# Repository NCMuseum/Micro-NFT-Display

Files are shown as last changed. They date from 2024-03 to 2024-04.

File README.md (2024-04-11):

An ESP32 based video player, that plays files from an SD card. Designed to play to a 128x64px OLED Screen.

# Parts List

Solderless Breadboard similar to this **https://core-electronics.com.au/solderless-breadboard-830-tie-point-zy-102.html**

LOLIN D32 Pro ESP32 Dev Board **https://www.aliexpress.com/item/32883116057.html**

Graphical OLED Display (128x64)  **https://www.pololu.com/product/3760**

SD Card to fit your animations

1 x 18650 Lithium Ion Cell (2600mah)

1 x power switch

Bunch of cabling

Optional Stand can be 3D printed from the STL in the "Design Files" folder

# Libraries Used

The EPS32 PNG Lib is included in the project folder & does not need to be installed as a library **https://github.com/lagunax/ESP32-upng** - modified to work with SD card instead of SPIFFS on the ESP32

The POLOLU OLED Lib needs to be installed in your Arduino Libraries folder https://github.com/pololu/pololu-oled-arduino

# Creating an animation file set from any video file

The ESP32 is not powerfull enough to play actual video files like .mp4, but we can preprocess any video file as sequenced PNG images. To do this you will need VLC Player **https://www.videolan.org/** After its installed you will need to configure on the Video Filters to output PNG files for you. Follow these steps to set it up:

1.  Open VLC Player
2.  Click on the TOOLS menu and select PREFERENCES
3.  Tick the "ALL" radio button in SHOW SETTINGS so you can see all teh settings at once
4.  Ont the left pane, scroll down to the bottom and DOUBLE CLICK on VIDEO
5.  On the right PANE tick "SCENE VIDEO FILTER"
6.  On the left pane scroll down to and click on "SCENE FILTER"
7.  On the right pane set the Image Format to "png"
8.  Image width to 128
9.  Image height to 64
10.  Filename prefix to whatever you want your animation to be called eg.. "MyAnimation_"
11.  If you want the PNG files output to specific folder enter it in the "Directory Path Prefix" field
12.  Set the recording Ration to 1
13.  Hit Save and restart VLC Player

To create your animations PNG files simply laod your video and hit play. The PNG files will be written to iether the source directory of your animation or the "Directory Path Prefix" you set in step 11. Once you have all your PNG files, create a folder on the SD card with the same name as you set in step 10. eg.. "MyAnimation". Move all the PNG files into this folder. 

Repeat the above for all your video files, but be sure to chagne the animation name prefix in step 11 and output folder path in step 11.

# Animation Pre requisites

Your animations must be in .png 24BIT colour, no transparency or anythhing else fancy. VLC will output by default as this
Make sure your source material is iether BW or Greyscale as the end render is in 1bit BW on the OLED Screen
The animations dimensions must be 128*64px 
The file names must look like this "AnimationName_00000.png" . Each animation can have up to a maximum of 99,999 frames.
The 1st frame must start at "_00001"
(You can also set a frame delay in the playlist file below if you want to slow down or speed up the playback)

# SDCARD Pre requisites

Format the SDCARD as one FAT32 Volume. Size isnt important. The root of the SDCard needs to have the following structure:
NO SPECIAL CHARECTORS IN ANIMATION NAMES

````
[DIR] AnimationOne
[DIR] AnimationTwo
[DIR] AnimationThree
[FILE] playlist
````

Example layout of one of the animation folders:

````
/AnimationOne
AnimationOne_00001.png
AnimationOne_00002.png
AnimationOne_00003.png
AnimationOne_00004.png
AnimationOne_..............
AnimationOne_00100.png
````

The Playlist file is set up as follows:
````
[Case Senstive Animation Name],[Number of Frame Files],[Delay in MILISECONDS between each frame];
[Case Senstive Animation Name],[Number of Frame Files],[Delay in MILISECONDS between each frame];
[Case Senstive Animation Name],[Number of Frame Files],[Delay in MILISECONDS between each frame];
....
````

Example layout of the "playlist" file

````
AnimationOne,100,10;AnimationTwo,200,20;AnimationThree,50,100;
````
You can set up a playlist toplay the same animation mulitple times, with any per frame delay and even reduce the animation frame count. EG.. this will play animation 1 (which has 100 frames in total) once at full speed, then at a slower speed, then only the 1st 50 frames at full speed

````
AnimationOne,100,1;AnimationOne,100,50;AnimationOne,50,1;
````

# Pinout for the Lolin D32 Pro ESP32 module

Micro CD Card PinOut for the Wemos D32 Pro as taken from  **https://www.wemos.cc/en/latest/_static/files/sch_d32_pro_v2.0.0.pdf** these are allready hardwired on this module

````
NS		1	NC
/CS		2	IO    04	TF_CS
DI		3	IO    23	MOSI
VDD		4	3.3V
CLK		5	IO    18	SCK
VSS		6	GND
D0		7	IO    19	MISO
RSV		8	NC
CD(1)	G	GND
````

PINOUT for OLED Screen

````
SCREEN  ESP32 Pin
VCC     +5V
GND     GND
CLK     22
MOS     26
RES     0
DC      21
CS      27
````

# Boot Up Flow

1.  Insert the SD CARD and power on
2.  The Pre prosessor will RUN over the playlist and compile a .STREAM file for each animation. You will see a new folder for each animation called "AnimationNameSTREAM" and inside it will be the stream file named "AnimationName.STREAM". The OLED screen will display a prgress bar for each animation as they are beeing processed. The preprocess is SLOW especialy with more than 100 files for each animation, however this step is only done once
3.  After all animation folders are processed the ESP32 will start playing the streams in the order listed in the file 'playlist'. You can put multiple entries for the same animation. Each animation has 2 options. Number of frames in the animation folder and the delay in MILISECONDS between each frame. 1ms delay is good for very smooth frame rates.

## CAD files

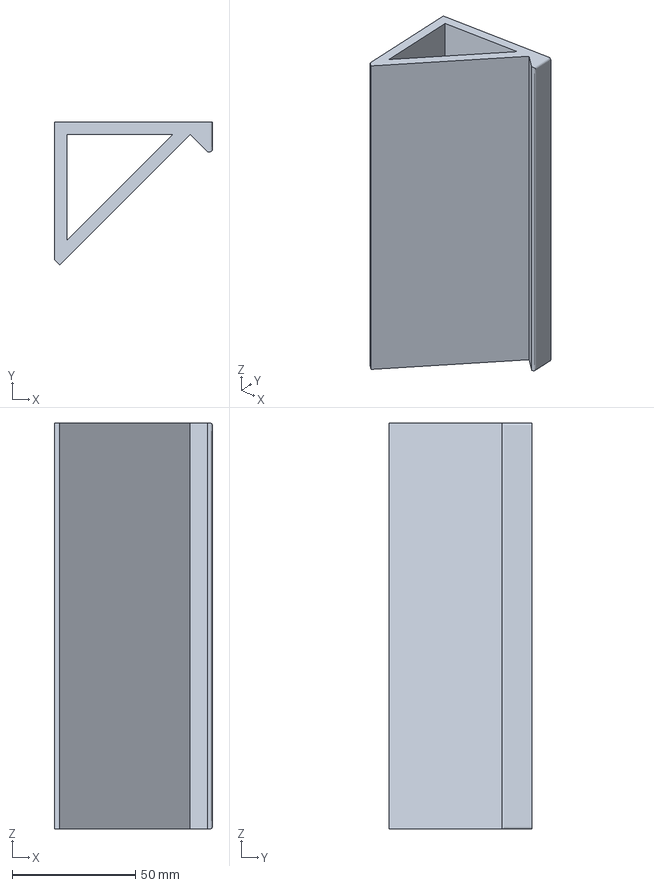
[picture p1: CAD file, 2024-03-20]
Design Files/MicroNFTDisplay_Stand.3mf
64.2 x 58.0 x 165.0 mm

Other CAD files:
Design Files/Stand.stl

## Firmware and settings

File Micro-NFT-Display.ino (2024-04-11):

/*
Micro CD Card PinOut for the Wemos D32 Pro as taken from 
https://www.wemos.cc/en/latest/_static/files/sch_d32_pro_v2.0.0.pdf

NS		1	NC
/CS		2	IO    04	TF_CS
DI		3	IO    23	MOSI
VDD		4	3.3V
CLK		5	IO    18	SCK
VSS		6	GND
D0		7	IO    19	MISO
RSV		8	NC
CD(1)	G	GND

PINOUT for OLED Screen
VCC     +5V
GND     GND
CLK     22
MOS     26
RES     0
DC      21
CS      27
 */

#include <WiFi.h>
#include "SPI.h"
#include <PololuOLED.h>
#include "FS.h"
#include "SD.h"
#include <string>
#include "upng.h"
#include "animationQue.h"

//Bitmaping Data
const byte rows=64, cols=128;    //rows = HEIGHT(Y)  cols = WIDTH(X)

//Colour Data
byte tempColour[3] = {0,0,0};

//Counters
unsigned short int cIndex=0, secondaryCIndex=0;
unsigned short int yCnt=0, xCnt=0;

//File Paths
char playListFile[] = "/playlist";
char integerCharString[] = "00000";

//PNG stuff
upng_t* upng;
unsigned short int xCount, yCount, imageSize, bufferIndex=0, testCnt=0;

//Card Stuff
uint8_t cardType=0;
long cardSize=0;

//Display
//The pins are specified in this order: CLK, MOS, RES, DC, CS.
PololuSH1106 display(22, 26, 0, 21, 27);
uint8_t graphics[1024];

//Pre Processor
File outputStream;
animationQue globalAnimationQue;

void setup()
{
  //Turn off WIFI we do not need it here
  WiFi.mode(WIFI_OFF); 
  
  //Init Serial
  Serial.begin(115200);
  Serial.printf("\r\n\r\n\r\nSystem Booting....\r\n");

  //Set up the OLED Display
  display.setLayout11x4WithGraphics(graphics);
  memset(graphics, 0, sizeof(graphics));
  display.noAutoDisplay();
  display.clear();
  display.display();

  //Init File System
  initFS();
  
  //Populate Animation List from SD Card file /playlist
  compilePlaylist();
  
  //Pre Process Multiple Frames into 1 File Stream
  compileStream();

}

void initFS()
{
  Serial.printf("\r\n\tSetting up SD Card FS...");
  
  SPI.begin();
  //begin(18, 19, 23, 4)
  SPI.setFrequency(40000000);
  if(! SD.begin(SS, SPI, 40000000, "/sd", 5, false) )
  {
    Serial.printf("\r\n\tSD Card Mount Failed...");
    clearCanvas();
    display.clear();
    display.print("SD MNT FAIL");
    display.display();
    while(true)
    {
      yield();
    }
  }
  cardType = SD.cardType();
  if(cardType == CARD_NONE)
  {
    Serial.printf("\r\n\tNo SD card attached!");
    clearCanvas();
    display.clear();
    display.print("NO SD CARD");
    display.display();
    return;
  }
}

void compilePlaylist()
{
  char* tempAnimationName;
  char* tempAnimationLength;
  char* tempAnimationDelay;
  char* playListFileBuffer;
  unsigned short int animationCount=0;
  unsigned short int aCnt=0, startI=0, endI=0, needleIndex=0, tempLength=0;
  PLNODE* queLocater;
  
  outputStream = SD.open(playListFile, "r");
  playListFileBuffer = new char[ outputStream.size() ];
  outputStream.readBytes(playListFileBuffer, outputStream.size());
  outputStream.close();
  Serial.printf("\r\nReadin\t[%s]", playListFileBuffer);

  //Grab number of animations in playlist
  animationCount = countNeedles(playListFileBuffer, ';');
  Serial.printf("\r\nAnimation Count in playlist file\t[%d]", animationCount);
  
  for(aCnt=0; aCnt<animationCount; aCnt++)
  {
    //Serial.printf("\r\nADD..");
    //locate 1st ','  animationName
    needleIndex++;
    endI = findNeedleCount(playListFileBuffer, ',', needleIndex);
    tempLength = endI-startI;
    tempAnimationName = new char[ tempLength+1 ];
    clearCharArray(tempAnimationName);
    memcpy(tempAnimationName, playListFileBuffer+startI, tempLength);
    tempAnimationName[tempLength]='\0';
    //locate 2nd ','  frameCount
    startI = endI+1;
    needleIndex++;
    endI = findNeedleCount(playListFileBuffer, ',', needleIndex);
    tempLength = endI-startI;
    tempAnimationLength = new char[ tempLength+1 ];
    clearCharArray(tempAnimationLength);
    memcpy(tempAnimationLength, playListFileBuffer+startI, tempLength);
    tempAnimationLength[tempLength]='\0';
    startI = endI+1;
    //locate 3rd ';'  delay
    endI = findNeedleCount(playListFileBuffer, ';', aCnt+1);
    tempLength = endI-startI;
    tempAnimationDelay = new char[ tempLength+1 ];
    clearCharArray(tempAnimationDelay);
    memcpy(tempAnimationDelay, playListFileBuffer+startI, tempLength);
    tempAnimationDelay[tempLength]='\0';
    startI = endI+1;
    globalAnimationQue.add(tempAnimationName, atoi(tempAnimationLength), atoi(tempAnimationDelay));
    yield();
    Serial.printf("\r\nItem\t[%d]\t[%s][%d][%d]", aCnt, tempAnimationName, atoi(tempAnimationLength), atoi(tempAnimationDelay) );
    //clear memory
    delete tempAnimationName;
    delete tempAnimationLength;
    delete tempAnimationDelay;
  }
  
  //Dump Animations
  Serial.printf("\r\n\tTotal Nodes\t%d", globalAnimationQue.totalNodes);
  for(aCnt=0; aCnt<globalAnimationQue.totalNodes; aCnt++)
  {
    queLocater = globalAnimationQue.findByID(aCnt);
    if(queLocater!=NULL)
    {
      Serial.printf("\r\nAnimation\t[%d][%d]\tName[", aCnt, queLocater->_nodeID );
      Serial.print(queLocater->_animationName);
      Serial.printf("]\tFolder Path[");
      Serial.print(queLocater->_folderPath);
      Serial.printf("]\tFull Path[");
      Serial.print(queLocater->_fullPath);
      Serial.printf("]\tFrame Count[");
      Serial.print(queLocater->_totalFrames);
      Serial.printf("]\tFrame Delay[");
      Serial.print(queLocater->_frameDelay);
      Serial.printf("]");
    }
    else
    {
      Serial.printf("\r\n\tNode [%d] not found!", aCnt);
    }
  }

}

unsigned short int countFiles(char* dirName)
{
    unsigned short fileCount=0;
    char* folderPath = new char[strlen(dirName)+2];
    
    folderPath[0] = '/';
    memcpy(folderPath+1, dirName, strlen(dirName));
    folderPath[strlen(dirName)+1] = 0;
    
    
    File root = SD.open(folderPath);
    File file = root.openNextFile();
    while(file)
    {
        fileCount++;
        file = root.openNextFile();
    }
    return fileCount;
}

void clearCharArray(char* charArray)
{
  unsigned short int charCount=0;
  for(charCount=0; charCount<strlen(charArray); charCount++)
  {
    charArray[charCount]=0;
  }
}
short int findNeedleCount(char* haystack, char needle, unsigned short needleCount)
{
  unsigned short int hayCount=0, nCount=0;
  for(hayCount; hayCount<strlen(haystack); hayCount++)
  {
    if(haystack[hayCount]==needle)
    {
      nCount++;
      if(nCount==needleCount)
      {
        return hayCount;
      }
    }
  }
  return -1;
}
short int countNeedles(char* haystack, char needle)
{
  unsigned short int found;
  unsigned short int hayCount;
  
  for(hayCount=0; hayCount<strlen(haystack); hayCount++)
  {
    if(haystack[hayCount]==needle)
    {
      found++;
    }
  }
  return found;
}

void compileStream()
{
  unsigned short int plCounter=0, postFrameCounter=0, charArrayIndex=0, bytesWriten=0;
  byte dirExists=0, streamExists=0;
  char * tempPathArray;
  char endOfFileChars[] = "_00001.png";
  unsigned short int barWidth=98;
  double progressBar = 0;
  PLNODE* queLocater;
  
  for(plCounter=0; plCounter<globalAnimationQue.totalNodes; plCounter++)
  {
    queLocater = globalAnimationQue.findByID(plCounter);
    if(queLocater!=NULL)
    {
      //Details of animationa re in 
      //  queLocater->_animationName
      //  queLocater->_fullPath     - full path of stream file to output to
      charArrayIndex=0;
      tempPathArray = new char[strlen(queLocater->_animationName)+2+strlen(queLocater->_animationName)+strlen(endOfFileChars)+1];
      clearCharArray(tempPathArray);
      tempPathArray[charArrayIndex] = '/';
      // [/]
      charArrayIndex++;
      memcpy(tempPathArray+charArrayIndex, queLocater->_animationName, strlen(queLocater->_animationName));
      // [/name]
      charArrayIndex+=strlen(queLocater->_animationName);
      // [/name/]
      tempPathArray[charArrayIndex] = '/';
      charArrayIndex++;
      memcpy(tempPathArray+charArrayIndex, queLocater->_animationName, strlen(queLocater->_animationName));
      charArrayIndex+=strlen(queLocater->_animationName);
      // [/name/name]
      memcpy(tempPathArray+charArrayIndex, endOfFileChars, strlen(endOfFileChars));
      // [/name/name_00000.png]
      charArrayIndex+=strlen(endOfFileChars);
      tempPathArray[charArrayIndex] = '\0';
      
      Serial.printf("\r\nProceessing frames in[");
      Serial.print(tempPathArray);
      Serial.printf("]");
      //check if output stream file exists
      if(!SD.exists(queLocater->_fullPath))
      {
          Serial.printf("\r\n\tCreating folder\t[%s]", queLocater->_streamFolderPath);
          SD.mkdir(queLocater->_streamFolderPath);
          Serial.printf("\r\n\tOpening File\t[%s]", queLocater->_fullPath);
          outputStream = SD.open(queLocater->_fullPath, FILE_WRITE);
          if(!outputStream)
          {
            Serial.printf("\r\n\tERROR - Can not open stream file for writing....");
            outputStream.close();
          }
          else
          {
            //Reset Progress Bar Width
            clearCanvas();
            display.clear();
            display.print("Compiling:");
            drawRectangle(16, 20, barWidth, 40);
            display.display();
            progressBar=0;
            
            //build the stream file
            for(postFrameCounter=0; postFrameCounter<queLocater->_totalFrames; postFrameCounter++)
            {
              fileNameIncremeneter(postFrameCounter+1, tempPathArray);
              upng = upng_new_from_file(SD, tempPathArray);
              if (upng != NULL)
              {
                upng_decode(upng);
                Serial.printf("\r\nFrame\t%d\t%d\tBytes\t", postFrameCounter, upng_get_size(upng));
                bytesWriten = outputStream.write(upng_get_buffer(upng), upng_get_size(upng));
                upng_free(upng);
                Serial.printf("Written\t%d bytes", bytesWriten);
                progressBar = ((double)postFrameCounter/(double)queLocater->_totalFrames)*((double)barWidth);
                drawSolidRectangle(16, 20, (uint8_t)round(progressBar), 40);
                display.display();
              }
            }
            outputStream.close();
          }
      }
      else  
      {
        Serial.printf("\r\n\tStream already exists for this item.");
      }
      delete tempPathArray; 
    }
  }
}

void fileNameIncremeneter(unsigned short int fileNameIndex, char* filePathString)
{
  char renameAtPointer=0, renameCounter=0;
  char namePlacer = 95; //95="_"

  //find the "_" in the file name fileNamePointer
  for(renameCounter=0; renameCounter<strlen(filePathString); renameCounter++)
  {
    if(filePathString[renameCounter]==namePlacer)
    {
      renameAtPointer = renameCounter+1;
      break;
    }
  }
  itoa(fileNameIndex, integerCharString, 10);  
  if(fileNameIndex<10)
  {
    filePathString[renameAtPointer] = 48;
    filePathString[renameAtPointer+1] = 48;
    filePathString[renameAtPointer+2] = 48;
    filePathString[renameAtPointer+3] = 48;
    filePathString[renameAtPointer+4] = integerCharString[0];
  }
  else if(fileNameIndex<100)
  {
    filePathString[renameAtPointer] = 48;
    filePathString[renameAtPointer+1] = 48;
    filePathString[renameAtPointer+2] = 48;
    filePathString[renameAtPointer+3] = integerCharString[0];
    filePathString[renameAtPointer+4] = integerCharString[1];
  }
  else if(fileNameIndex<1000)
  {
    filePathString[renameAtPointer] = 48;
    filePathString[renameAtPointer+1] = 48;
    filePathString[renameAtPointer+2] = integerCharString[0];
    filePathString[renameAtPointer+3] = integerCharString[1];
    filePathString[renameAtPointer+4] = integerCharString[2];
  }
  else if(fileNameIndex<10000)
  {
    filePathString[renameAtPointer] = 48;
    filePathString[renameAtPointer+1] = integerCharString[0];
    filePathString[renameAtPointer+2] = integerCharString[1];
    filePathString[renameAtPointer+3] = integerCharString[2];
    filePathString[renameAtPointer+4] = integerCharString[3];
  }
  else if(fileNameIndex<100000)
  {
    filePathString[renameAtPointer] = integerCharString[0];
    filePathString[renameAtPointer+1] = integerCharString[1];
    filePathString[renameAtPointer+2] = integerCharString[2];
    filePathString[renameAtPointer+3] = integerCharString[3];
    filePathString[renameAtPointer+4] = integerCharString[4];
  }
}

void loop()
{
	unsigned short int streamCount=0;
	while(true)
	{
	  for(streamCount=0; streamCount<globalAnimationQue.totalNodes; streamCount++)
	  {
		  playStream(streamCount);
	  }
	  yield();
	}
}

void playStream(unsigned short int streamID)
{
  unsigned short int frameIndex=0, bufferIndex=0;
  char* frameBuffer = new char[rows*cols*3];
  unsigned short int pixelValue=0;
  unsigned short int colourLevelFilter = 300;

  PLNODE* queLocater = globalAnimationQue.findByID(streamID);
  if(queLocater!=NULL)
  {
    display.clear();
    Serial.printf("\r\nPlaying [");
    Serial.print(queLocater->_fullPath);
    Serial.printf("] Que Index[%d]\tFrames to Play[%d]\tFrameDelay[%d]", streamID, queLocater->_totalFrames, queLocater->_frameDelay);
    outputStream = SD.open(queLocater->_fullPath, "r");
    for(frameIndex=0; frameIndex<queLocater->_totalFrames; frameIndex++)
    {
      outputStream.readBytes(frameBuffer, rows*cols*3);
      for(yCount=0; yCount<rows; yCount++)
      {
        for(xCount=0; xCount<cols; xCount++)
        {
          memcpy(tempColour, frameBuffer+bufferIndex, 3);
          pixelValue = tempColour[0]+tempColour[1]+tempColour[2];
          if(pixelValue>colourLevelFilter)
          {
            setPixel(xCount, yCount, true);
          }
          else
          {
            setPixel(xCount, yCount, false);
          }
          bufferIndex+=3;
        }
      }
      bufferIndex=0;
      display.display();
      clearCanvas();
      if(queLocater->_frameDelay==0){yield();}
      else{delay(queLocater->_frameDelay);}
    }
    outputStream.close();
  } 
  delete frameBuffer;
}


//OLED SCREEN Helper Functions
void clearCanvas()
{
  unsigned short int index=0;
  for(index=0; index<1024; index++)
  {
    graphics[index]=0;
  }
}

void setPixel(uint8_t x, uint8_t y, bool value)
{
  if (x >= cols || y >= rows) { return; }
  if (value)
  {
    graphics[x + (y >> 3) * cols] |= 1 << (y & 7);
  }
  else
  {
    graphics[x + (y >> 3) * cols] &= ~(1 << (y & 7));
  }
}

void drawSolidRectangle(uint8_t topLeftX, uint8_t topLeftY, uint8_t width, uint8_t height)
{
  if (topLeftX >= cols) { return; }
  if (width > (uint8_t)(cols - topLeftX)) { width = cols - topLeftX; }

  uint8_t y = topLeftY;
  for (uint8_t page = 0; page < 8; page++)
  {
    if (height == 0) { return; }
    if (y >= 8) { y -= 8; continue; }

    uint8_t heightOnThisPage = min(height, (uint8_t)(8 - y));
    uint8_t mask = ((1 << heightOnThisPage) - 1) << y;
    for (uint8_t x = topLeftX; x < topLeftX + width; x++)
    {
      graphics[x + cols * page] |= mask;
    }
    y = 0;
    height -= heightOnThisPage;
  }
}

void drawRectangle(uint8_t topLeftX, uint8_t topLeftY, uint8_t width, uint8_t height)
{
  for (uint8_t x = topLeftX; x < topLeftX + width; x++)
  {
    setPixel(x, topLeftY, 1);
    setPixel(x, topLeftY + height - 1, 1);
  }

  for (uint8_t y = topLeftY; y < topLeftY + height; y++)
  {
    setPixel(topLeftX, y, 1);
    setPixel(topLeftX + width - 1, y, 1);
  }
}

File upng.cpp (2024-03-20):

/*
uPNG -- derived from LodePNG version 20100808

Copyright (c) 2005-2010 Lode Vandevenne
Copyright (c) 2010 Sean Middleditch

This software is provided 'as-is', without any express or implied
warranty. In no event will the authors be held liable for any damages
arising from the use of this software.

Permission is granted to anyone to use this software for any purpose,
including commercial applications, and to alter it and redistribute it
freely, subject to the following restrictions:

		1. The origin of this software must not be misrepresented; you must not
		claim that you wrote the original software. If you use this software
		in a product, an acknowledgment in the product documentation would be
		appreciated but is not required.

		2. Altered source versions must be plainly marked as such, and must not be
		misrepresented as being the original software.

		3. This notice may not be removed or altered from any source
		distribution.
*/

#include "upng.h"

#define MAKE_BYTE(b) ((b) & 0xFF)
#define MAKE_DWORD(a,b,c,d) ((MAKE_BYTE(a) << 24) | (MAKE_BYTE(b) << 16) | (MAKE_BYTE(c) << 8) | MAKE_BYTE(d))
#define MAKE_DWORD_PTR(p) MAKE_DWORD((p)[0], (p)[1], (p)[2], (p)[3])

#define CHUNK_IHDR MAKE_DWORD('I','H','D','R')
#define CHUNK_IDAT MAKE_DWORD('I','D','A','T')
#define CHUNK_IEND MAKE_DWORD('I','E','N','D')

#define FIRST_LENGTH_CODE_INDEX 257
#define LAST_LENGTH_CODE_INDEX 285

#define NUM_DEFLATE_CODE_SYMBOLS 288	/*256 literals, the end code, some length codes, and 2 unused codes */
#define NUM_DISTANCE_SYMBOLS 32	/*the distance codes have their own symbols, 30 used, 2 unused */
#define NUM_CODE_LENGTH_CODES 19	/*the code length codes. 0-15: code lengths, 16: copy previous 3-6 times, 17: 3-10 zeros, 18: 11-138 zeros */
#define MAX_SYMBOLS 288 /* largest number of symbols used by any tree type */

#define DEFLATE_CODE_BITLEN 15
#define DISTANCE_BITLEN 15
#define CODE_LENGTH_BITLEN 7
#define MAX_BIT_LENGTH 15 /* largest bitlen used by any tree type */

#define DEFLATE_CODE_BUFFER_SIZE (NUM_DEFLATE_CODE_SYMBOLS * 2)
#define DISTANCE_BUFFER_SIZE (NUM_DISTANCE_SYMBOLS * 2)
#define CODE_LENGTH_BUFFER_SIZE (NUM_DISTANCE_SYMBOLS * 2)

#define SET_ERROR(upng,code) do { (upng)->error = (code); (upng)->error_line = __LINE__; } while (0)

#define upng_chunk_length(chunk) MAKE_DWORD_PTR(chunk)
#define upng_chunk_type(chunk) MAKE_DWORD_PTR((chunk) + 4)
#define upng_chunk_critical(chunk) (((chunk)[4] & 32) == 0)

typedef enum upng_state {
	UPNG_ERROR		= -1,
	UPNG_DECODED	= 0,
	UPNG_HEADER		= 1,
	UPNG_NEW		= 2
} upng_state;

typedef enum upng_color {
	UPNG_LUM		= 0,
	UPNG_RGB		= 2,
	UPNG_PAL		= 3,
	UPNG_LUMA		= 4,
	UPNG_RGBA		= 6
} upng_color;

typedef struct upng_source {
	const unsigned char*	buffer;
	unsigned long			size;
	char					owning;
} upng_source;

struct upng_t {
	unsigned		width;
	unsigned		height;

	upng_color		color_type;
	unsigned		color_depth;
	upng_format		format;

	unsigned char*	buffer;
	unsigned long	size;

	upng_error		error;
	unsigned		error_line;

	upng_state		state;
	upng_source		source;
};

typedef struct huffman_tree {
	unsigned* tree2d;
	unsigned maxbitlen;	/*maximum number of bits a single code can get */
	unsigned numcodes;	/*number of symbols in the alphabet = number of codes */
} huffman_tree;

static const unsigned LENGTH_BASE[29] = {	/*the base lengths represented by codes 257-285 */
	3, 4, 5, 6, 7, 8, 9, 10, 11, 13, 15, 17, 19, 23, 27, 31, 35, 43, 51, 59,
	67, 83, 99, 115, 131, 163, 195, 227, 258
};

static const unsigned LENGTH_EXTRA[29] = {	/*the extra bits used by codes 257-285 (added to base length) */
	0, 0, 0, 0, 0, 0, 0, 0, 1, 1, 1, 1, 2, 2, 2, 2, 3, 3, 3, 3, 4, 4, 4, 4, 5,
	5, 5, 5, 0
};

static const unsigned DISTANCE_BASE[30] = {	/*the base backwards distances (the bits of distance codes appear after length codes and use their own huffman tree) */
	1, 2, 3, 4, 5, 7, 9, 13, 17, 25, 33, 49, 65, 97, 129, 193, 257, 385, 513,
	769, 1025, 1537, 2049, 3073, 4097, 6145, 8193, 12289, 16385, 24577
};

static const unsigned DISTANCE_EXTRA[30] = {	/*the extra bits of backwards distances (added to base) */
	0, 0, 0, 0, 1, 1, 2, 2, 3, 3, 4, 4, 5, 5, 6, 6, 7, 7, 8, 8, 9, 9, 10, 10,
	11, 11, 12, 12, 13, 13
};

static const unsigned CLCL[NUM_CODE_LENGTH_CODES]	/*the order in which "code length alphabet code lengths" are stored, out of this the huffman tree of the dynamic huffman tree lengths is generated */
= { 16, 17, 18, 0, 8, 7, 9, 6, 10, 5, 11, 4, 12, 3, 13, 2, 14, 1, 15 };
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
